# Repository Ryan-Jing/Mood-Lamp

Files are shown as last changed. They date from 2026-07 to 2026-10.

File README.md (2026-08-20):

# Mood-Lamp

Synchronized mood lamp between two paired devices. Each lamp is a Seeed XIAO ESP32-C3 with a
single WS2812B RGB LED and a dual-stage button. A lamp shows its **peer's** mood by default; you
set your own mood with the button, it's pushed to a small server, and the peer lamp polls and
renders it.

- **Firmware** (`Firmware/`) — PlatformIO + Arduino, two FreeRTOS tasks (UI + networking). See [`Firmware/README.md`](Firmware/README.md).
- **Server** (`Server/`) — FastAPI + SQLite on a Raspberry Pi, exposed publicly via Tailscale Funnel.
- **Utils** (`Utils/`) — `moods.yaml` (mood source of truth), the mood-header generator, and the BLE Wi-Fi provisioning script. See [`Utils/README.md`](Utils/README.md).
- **Docs** (`Docs/`) — architecture and CI/CD notes.
- **Electrical** / **Mechanical** — KiCad project and the printable enclosure STLs.

---

## Setup guide

### 1. Flash the firmware (first time only)

Skip to step 2 if the lamp is already flashed. Requires [PlatformIO Core](https://platformio.org/install/cli)
(`pio`) on your computer.

```bash
cd Firmware
```

```bash
cp include/secrets.example.h include/secrets.h
```

Open `include/secrets.h` and fill in `SERVER_URL`, `DEVICE_TOKEN` (one per lamp, from
`Server/database_init.py`), and `ROOT_CA`. Then connect the lamp by USB-C and flash it:

```bash
pio run -e seeed_xiao_esp32c3 -t upload
```

Do **not** press the lamp's button while flashing.

### 2. Power the lamp over USB-C

Plug the XIAO's USB-C port into any 5 V USB source (charger, laptop, power bank). The lamp boots
in about two seconds and the LED tells you where it is:

| LED | Meaning | What to do |
|---|---|---|
| Cyan blink | BLE provisioning — no Wi-Fi credentials saved | Go to step 3 |
| Warm-white breath | Connected, peer hasn't set a mood yet | Nothing, it's ready |
| Animated mood colour | Connected, showing the peer's mood | Nothing, it's ready |
| Orange blink | Wi-Fi problem | Re-provision (step 3) or check the network |

If the lamp already has credentials but you want to re-provision, hold the button fully pressed
for 5 seconds to force BLE provisioning on.

### 3. Send Wi-Fi credentials with `Utils/provision.py`

Do this on a computer with Bluetooth, within a few metres of the lamp, while the LED is blinking
cyan. Provisioning stays open for 2 minutes per session.

```bash
cd /path/to/Mood-Lamp
```

```bash
python3 -m venv .venv
```

```bash
source .venv/bin/activate
```

```bash
pip install bleak
```

```bash
python3 Utils/provision.py
```

The script prompts for the network name and password, finds the lamp advertising as `MoodLamp`,
and writes the credentials over BLE:

```
Wi-Fi SSID: MyNetwork
Wi-Fi password: ********
Scanning for 'MoodLamp' (the lamp LED should be blinking cyan)...
Connected. Sending credentials...
Credentials sent. Waiting for the lamp to connect to Wi-Fi...
Lamp status: connecting
```

The lamp saves the credentials to flash (they survive reboots and power loss), leaves BLE, and
joins the network. The LED stops blinking cyan within a few seconds. Notes:

- 2.4 GHz networks only — the ESP32-C3 has no 5 GHz radio.
- If the lamp isn't found, it's not in provisioning mode; hold the button fully pressed for
  5 seconds and run the script again.
- `python3 Utils/ble_check.py` lists nearby BLE devices if you want to confirm the lamp is
  advertising at all.

### 4. Using the button

The button is a dual-action pushbutton: pressing part-way is a **half press** (first detent), and
pressing all the way down is a **full press**. Every gesture fires when you *release*.

| Gesture | What it does |
|---|---|
| Half tap | Only in mood-select mode: step to the next mood |
| Full tap | Enter mood-select mode → then confirm the mood and send it to your peer |
| Full press, hold 5 s | Turn BLE provisioning on (or off if it's already on) |
| Full press, hold 10 s | Erase the saved Wi-Fi credentials and reopen BLE provisioning |

To set your mood:

1. **Full tap** — the LED switches from your peer's mood to your own. (This only works while the
   lamp is connected; if it isn't, nothing happens.)
2. **Half tap** repeatedly until the LED shows the mood you want. It wraps around from Working
   back to Excited.
3. **Full tap** — the mood is posted to the server and the LED goes back to showing your peer's
   mood. Their lamp picks it up within 10 seconds.

Half taps do nothing outside mood-select mode, so brushing the button won't change anything. Hold
times are measured from the moment the *full* stage engages, so resting at the half press first
doesn't count toward the 5 s and 10 s timers.

---

## Moods

Colours and patterns are defined in [`Utils/moods.yaml`](Utils/moods.yaml) and generated into
`Firmware/include/moods.h`. The ID below is the `mood_id` the firmware and server exchange.

Three **status** moods are shown by the lamp but are never user-selectable (mood-select skips
them):

| ID | Mood | Colour | Pattern | Period |
|---|---|---|---|---|
| 0 | Idle / default | soft warm white | breath | 6000 ms |
| 1 | BLE provisioning | cyan | blink | 1000 ms |
| 2 | No Wi-Fi | reddish orange | blink | 500 ms |

The user-selectable moods:

| ID | Mood | Colour(s) | Pattern | Period |
|---|---|---|---|---|
| 3 | Excited | bright yellow | breath | 1000 ms |
| 4 | Happy | rainbow (7 colours) | fade | 1000 ms |
| 5 | Sad | dark blue | breath | 3000 ms |
| 6 | Upset | dark red | breath | 1000 ms |
| 7 | Anxious | dark purple → purple → violet → red | breath alternate | 800 ms |
| 8 | Deep Breaths | dark green | breath | 8000 ms |
| 9 | Love | dark pink → pink → bright pink → light purple | fade | 1000 ms |
| 10 | Heepy | bright pink | blink | 800 ms |
| 11 | Hungry | dark brownish yellow | breath | 1000 ms |
| 12 | Tired | dark red ↔ dark orange | fade | 10000 ms |
| 13 | Working | warm orange | solid | — |

Patterns: `solid`, `blink` (on for the first half of the period), `breath` (dim → bright → dim),
`alternate` (hard switch between colours), `fade` (smooth cross-fade), and `breath_alternate`
(one breath per colour, advancing to the next each cycle).

To change moods, edit [`Utils/moods.yaml`](Utils/moods.yaml), then regenerate the firmware header
and re-flash:

```bash
cd /path/to/Mood-Lamp
```

```bash
python3 Utils/generate_moods.py
```

Both lamps must run the same mood table — IDs are what travel over the wire, so a lamp with an
older table will render the wrong mood.

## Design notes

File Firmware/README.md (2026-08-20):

# Mood Lamp — Firmware

Firmware for a two-device "mood lamp" pair. Each lamp is a Seeed XIAO ESP32-C3 with one
WS2812B RGB LED and one dual-stage pushbutton. A lamp's default display is the **peer's**
mood: the user sets their own mood locally with the button, the firmware pushes it to a
shared server over HTTPS, and the peer lamp polls the server and renders it as a
colour/pattern. Wi-Fi credentials are provisioned over BLE with `Utils/provision.py`.

For end-user setup (power, provisioning, button use), see the
[root README](../README.md#setup-guide); this document covers the firmware itself.

---

## Hardware

| Component | Part | Connection |
|---|---|---|
| MCU | Seeed XIAO ESP32-C3 (single-core RISC-V, Wi-Fi + BLE) | USB-C for power/flash/serial |
| RGB LED | SparkFun WS2812B Breakout (part 13282) | DIN → `D0` (GPIO2), DO unconnected |
| Button | E-Switch **PB300DTQ** dual-action pushbutton | pin 1 → GND, pin 2 → `D2` (GPIO4), pin 3 → `D1` (GPIO3) |

### Wiring notes

- **WS2812B**: single-wire self-clocked protocol, driven by the Adafruit NeoPixel library
  (`NEO_GRB + NEO_KHZ800`). Power the LED from **3.3 V**, not 5 V: with a 5 V supply the
  ~3.5 V logic-high threshold is above the ESP32-C3's 3.3 V output. At 3.3 V supply the LED
  is in spec, slightly dimmer.
- **Button**: both stage pins use internal pull-ups (`INPUT_PULLUP`), active low. No
  external resistors needed.
- **`D0` is GPIO2, an ESP32-C3 strapping pin** — it must be high or floating at reset. The
  WS2812B's DIN is a high-impedance input and the pin is only driven after boot, so normal
  boot and flashing are unaffected.
- Pin assignments live in `src/hal/led.cpp` (`LED_DIN_PIN`) and `src/hal/button.cpp`
  (`button_position_one` / `button_position_two`).

---

## Project setup

Built with [PlatformIO](https://platformio.org/) on the Arduino framework.

```sh
cd Firmware

# 1. Create your secrets file (never committed)
cp include/secrets.example.h include/secrets.h
#    ...then fill in SERVER_URL, DEVICE_TOKEN, and ROOT_CA (PEM string)

# 2. Build + flash + monitor (XIAO ESP32-C3 over USB)
pio run -e seeed_xiao_esp32c3 -t upload
pio device monitor            # 115200 baud

# 3. Run host-side unit tests (no hardware needed)
pio test -e native
```

Library dependencies (resolved automatically by PlatformIO): Adafruit NeoPixel,
NimBLE-Arduino, ArduinoJson.

`include/moods.h` is **auto-generated** — edit `Utils/moods.yaml` at the repo root and
re-run the generator (`Utils/generate_moods.py`) instead of editing it by hand.

Debug logging is controlled by `PRINT_DEBUG` in `include/config.h`; comment it out for a
quiet build. Note that with it enabled, received Wi-Fi credentials are echoed to serial.

---

## File structure

```
Firmware/
├── platformio.ini            # Envs: seeed_xiao_esp32c3 (target), native (unit tests)
├── include/
│   ├── config.h              # Timeouts, poll interval, retry limits, PRINT_DEBUG
│   ├── moods.h               # AUTO-GENERATED mood enum + colour/pattern table
│   ├── secrets.h             # Server URL, device token, root CA (from secrets.example.h)
│   ├── state.h               # LampState / NetState types + shared task interface
│   ├── hal/
│   │   ├── button.h          # ButtonState/ButtonEvent enums, gesture handler API
│   │   ├── led.h             # LED driver API
│   │   └── led_effects.h     # Pattern animation (pure logic, host-testable)
│   └── net/
│       ├── api.h             # HTTP mood-server client API
│       ├── ble.h             # BLE provisioning service API
│       └── wifi.h            # Wi-Fi connect + NVS credential storage API
├── src/
│   ├── main.cpp              # Entry point; vLampTask + vCommsTask state machines
│   ├── state.cpp             # Mutex/queue-backed shared state between the two tasks
│   ├── hal/
│   │   ├── button.cpp        # Debounce, press-cycle event decoding, gesture handlers
│   │   ├── led.cpp           # WS2812B driver (Adafruit NeoPixel, GPIO2)
│   │   └── led_effects.cpp   # Solid/blink/breath/alternate/fade frame computation
│   └── net/
│       ├── api.cpp           # HTTPS POST/GET of moods (Bearer auth, ETag polling)
│       ├── ble.cpp           # NimBLE provisioning service (SSID/pass/apply/status)
│       └── wifi.cpp          # STA connect + Preferences (NVS) credential store
├── test/
│   └── test_logic/           # Unity tests for led_effects (run via `pio test -e native`)
└── docs/                     # Doxygen styling (see Doxyfile)
```

### Architecture

Two FreeRTOS tasks, created in `setup()`, communicate only through the mutex/queue-guarded
interface in `state.cpp`:

- **`vLampTask`** — reads the button, runs the `AppState` machine, renders the LED every
  10 ms. Never blocks on the network.
- **`vCommsTask`** — runs the `CommsStatus` machine: BLE provisioning, Wi-Fi connection,
  SNTP time sync, and server sync. Receives user commands (start/stop BLE, clear Wi-Fi)
  from the lamp task via a queue.

---

## Button (PB300DTQ)

The E-Switch **PB300DTQ** is a momentary double-action pushbutton: the first circuit
closes at mid travel and the second at full travel (2.0 mm total; ~600 g to the first
detent, ~1150 g to the second). Pin 1 is common (GND); pin 2 grounds at **half press**
(→ `D2`) and pin 3 grounds additionally at **full press** (→ `D1`). At full press both
signal pins are shorted to GND.

### Debounce and states

`get_button_state()` debounces each stage pin independently (50 ms) and folds them into
one `ButtonState`:

| `D2` (half stage) | `D1` (full stage) | State |
|---|---|---|
| HIGH | HIGH | `BUTTON_RELEASED` |
| LOW | HIGH | `BUTTON_HALF_PRESSED` |
| any | LOW | `BUTTON_FULL_PRESSED` |

The full stage alone decides `BUTTON_FULL_PRESSED`, since a full press grounds both pins.

### Events

A full press mechanically passes through the half stage on the way down *and* up, so raw
states can't be used as gestures directly. `update_button_event()` tracks each press
cycle (latching whether it ever reached full) and emits **one event on release**:

| Event | Meaning |
|---|---|
| `BUTTON_EVENT_HALF_TAP` | Pressed and released without ever reaching the full stage |
| `BUTTON_EVENT_FULL_TAP` | Reached full, released before `BLE_SET_TIMER` (5 s) |
| `BUTTON_EVENT_FULL_HOLD_BLE` | Full stage held ≥ 5 s and < 10 s |
| `BUTTON_EVENT_FULL_HOLD_WIFI` | Full stage held ≥ `WIFI_CLEAR_TIMER` (10 s) |

Hold time is measured from when the **full** stage engages — resting at half press first
doesn't count toward the timers.

### Gesture map

`handle_user_button_commands()` consumes global gestures first; per-state handlers
(`show_mood_button_handle` / `select_mood_button_handle`) get unconsumed events.

| Gesture | SHOW_MOOD | SELECT_MOOD | BLE provisioning/connected |
|---|---|---|---|
| Half tap | — | Cycle to next mood | — |
| Full tap | Enter SELECT_MOOD (requires `NET_CONNECTED`) | Confirm: post mood, back to SHOW_MOOD | **Exit BLE immediately** (`USER_COMMAND_STOP_BLE`) |
| Full hold 5 s | Start BLE provisioning | Start BLE provisioning | Stop BLE |
| Full hold 10 s | Clear Wi-Fi credentials → re-enter provisioning | same | same |

Half taps are deliberately inert outside SELECT_MOOD: the half stage is easy to hit, so
casual presses in SHOW_MOOD do nothing.

### Lamp application states (`AppState`)

| State | LED shows | Entered by |
|---|---|---|
| `SHOW_MOOD` | Peer's mood (or `IDLE` pattern if disconnected) | Default; comms status `NET_*` |
| `SELECT_MOOD` | Your own candidate mood while scrolling | Full tap in SHOW_MOOD |
| `BLE_STATUS` | `BLE` pattern (cyan blink) | Comms status `BLE_PROVISIONING` / `BLE_CONNECTED` |
| `NET_STATUS` | `NO_WIFI` pattern (orange blink) | (reserved) |

`SELECT_MOOD` is exited by confirming a mood, or automatically if the network drops.

---

## LED (WS2812B)

One WS2812B pixel on `D0` (GPIO2), driven by Adafruit NeoPixel. Every lamp-task
iteration calls `led_render(mood)`, which looks up the mood's `MoodDefinition` (up to
`MAX_MOOD_COLOURS` = 8 RGB colours, a pattern, and a period) and computes the current frame
with `mood_frame()` in `led_effects.cpp` — pure logic with no hardware dependency, which is
what the native unit tests cover. `led_render` only re-latches the pixel when the computed
colour changes.

Patterns: `SOLID`, `BLINK` (on for the first half of the period), `BREATH` (raised-cosine,
gamma-corrected brightness ramp), `ALTERNATE` (hard switch between colours each period),
`FADE` (smooth cross-fade between colours), `BREATH_ALTERNATE` (one breath per colour,
advancing to the next each cycle). A `period` of 0 renders the base colour solid.

The mood table is generated from `Utils/moods.yaml` into `moods.h`, and the enum index is
the `mood_id` exchanged with the server (`MOOD_COUNT` = 14). The first three entries are
**status** moods, never user-selectable; scrolling to pick a mood starts at
`FIRST_SELECTABLE_MOOD` (`MOOD_1`) and wraps back to it:

| ID | Enum | Mood | Colour(s) | Pattern | Period |
|---|---|---|---|---|---|
| 0 | `IDLE` | Default | soft warm white | breath | 6000 ms |
| 1 | `BLE` | BLE Provisioning | cyan | blink | 1000 ms |
| 2 | `NO_WIFI` | No Wi-Fi | reddish orange | blink | 500 ms |
| 3 | `MOOD_1` | Excited | bright yellow | breath | 1000 ms |
| 4 | `MOOD_2` | Happy | rainbow (7 colours) | fade | 1000 ms |
| 5 | `MOOD_3` | Sad | dark blue | breath | 3000 ms |
| 6 | `MOOD_4` | Upset | dark red | breath | 1000 ms |
| 7 | `MOOD_5` | Anxious | dark purple → purple → violet → red | breath alternate | 800 ms |
| 8 | `MOOD_6` | Deep Breaths | dark green | breath | 8000 ms |
| 9 | `MOOD_7` | Love | dark pink → pink → bright pink → light purple | fade | 1000 ms |
| 10 | `MOOD_8` | Heepy | bright pink | blink | 800 ms |
| 11 | `MOOD_9` | Hungry | dark brownish yellow | breath | 1000 ms |
| 12 | `MOOD_10` | Tired | dark red ↔ dark orange | fade | 10000 ms |
| 13 | `MOOD_11` | Working | warm orange | solid | — |

---

## Communication

### Comms state machine (`CommsStatus`, in `vCommsTask`)

At boot the task starts in `BLE_PROVISIONING` if NVS holds no credentials, otherwise in
`NET_CONNECTING`.

| State | What it does | Leaves to |
|---|---|---|
| `BLE_PROVISIONING` | Advertises as `MoodLamp` and waits for a client | `BLE_CONNECTED` on connect; after the 2 min timeout or a full tap, back to `NET_CONNECTING` (saved creds) or `NET_DISCONNECTED` (none) |
| `BLE_CONNECTED` | Receives SSID/password, saves them to NVS on Apply | `NET_CONNECTING` once credentials are applied; `BLE_PROVISIONING` if the client drops |
| `NET_CONNECTING` | Joins Wi-Fi (20 s timeout per attempt), then waits for SNTP time sync (needed for TLS certificate validation); retries every 5 s | `NET_CONNECTED` on success; `NET_DISCONNECTED` after 12 failed attempts |
| `NET_CONNECTED` | Uploads any locally-set mood and polls the peer's mood | `NET_CONNECTING` after 5 consecutive API failures or a Wi-Fi drop |
| `NET_DISCONNECTED` | Idle; the lamp shows the `IDLE` pattern | Only by user command (button) |

A 5 s full hold starts or stops BLE provisioning from any state; a 10 s full hold clears
the stored credentials and returns to `BLE_PROVISIONING`.

### BLE provisioning

NimBLE GATT server, device name `MoodLamp`, active for at most 2 minutes per session
(`BLE_PROVISIONING_TIMEOUT_MS`). Service `9a1e0000-8f4a-4b1c-9e2a-1234567890ab`:

| Characteristic | UUID suffix | Access | Purpose |
|---|---|---|---|
| SSID | `...0001` | write | Wi-Fi SSID (max 32 chars) |
| Password | `...0002` | write | Wi-Fi password (max 63 chars) |
| Apply | `...0003` | write | Any write commits the credentials |
| Status | `...0004` | read/notify | `"provisioning"` → `"connecting"` |

Flow: `Utils/provision.py` writes SSID and password, then writes Apply. The comms task saves
the credentials to NVS (`Preferences`, namespace `wifi`), notifies `"connecting"` on
Status, tears down BLE, and moves to `NET_CONNECTING`. Credentials persist across reboots;
a 10 s full-press hold wipes them and returns to provisioning.

### Server API

HTTPS with certificate pinning (`ROOT_CA`) and per-device Bearer token auth
(`DEVICE_TOKEN`), both from `secrets.h`. The server pairs exactly two devices; "peer"
below is resolved server-side from the token. 5 s request timeout (`API_TIMEOUT_MS`).

**`POST /v1/mood`** — publish this lamp's mood.

```json
{ "mood_id": 6 }
```

**`GET /v1/peer/mood`** — fetch the peer's mood, polled every 10 s
(`PEER_POLL_INTERVAL_MS`). Responses are versioned: the lamp sends
`If-None-Match: "<version>"` and the server replies `304 Not Modified` when nothing
changed, so steady-state polling transfers no body. On change:

```json
{ "mood_id": 6, "version": 42 }
```

`mood_id` is validated against `MOOD_COUNT` before use; malformed responses count toward
the retry limit like HTTP errors.

### Hosting & the `ts.net` DNS gotcha

The server runs on a Raspberry Pi (CM5) and is exposed to the public internet via **Tailscale
Funnel**, so `SERVER_URL` is a `*.ts.net` hostname reachable from anywhere — the ESP32 never
joins the tailnet, it just makes ordinary HTTPS requests to the public Funnel URL.

One gotcha worth knowing: many home routers' **DNS rebind protection blocks `*.ts.net`**
(Tailscale names can resolve into the CGNAT `100.64.0.0/10` range, which rebind protection
treats as suspicious), so the router refuses to resolve the server hostname even though public
resolvers do. Symptom on the lamp:

```
[E][WiFiGeneric.cpp:1583] hostByName(): DNS Failed for <server>.ts.net
```

The firmware works around this by forcing public DNS (`8.8.8.8` / `1.1.1.1`) via
`force_public_dns()` in `wifi.cpp`. It must run **after** `WL_CONNECTED` — once DHCP has
assigned its own DNS — otherwise DHCP overwrites the override. It re-applies on every
`wifi_connect()`, so a DHCP lease renewal that resets DNS self-heals on the next reconnect.

If a lamp on a **new** network still fails after this, that router is *intercepting* outbound
DNS (forcing port 53 through itself); disable DNS rebind protection or allowlist `ts.net` on
that router. Quick confirm via `PRINT_DEBUG`: `DNS1: 8.8.8.8` plus `example.com` resolving but
the server failing pinpoints the `ts.net`-specific block.

> Verifying the server side (from any machine): `dig @8.8.8.8 <server>.ts.net` should return
> Tailscale Funnel IPs, and `curl https://<server>.ts.net/v1/health` should return
> `{"ok":true}`. On the Pi, `tailscale funnel status` should show `/ proxy` to the uvicorn port.

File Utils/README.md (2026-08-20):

# Utils

Host-side tooling: the mood definitions and their code generator, plus the BLE Wi-Fi
provisioning script.

| File | Purpose |
|---|---|
| `moods.yaml` | Single source of truth for every mood's colour(s), pattern, and period |
| `generate_moods.py` | Bakes `moods.yaml` into `Firmware/include/moods.h` |
| `provision.py` | Sends Wi-Fi credentials to a lamp over BLE |
| `ble_check.py` | Lists nearby BLE devices — used to confirm a lamp is advertising |
| `Button-Test/` | Standalone PlatformIO sketch for bench-testing the dual-stage button |

Run every script from the repo root; they resolve paths relative to their own location.

---

## `provision.py`

Connects to a Mood Lamp over BLE and hands it a Wi-Fi SSID and password, so the lamp can
join the network and reach the server. It targets the GATT service in
`Firmware/src/net/ble.cpp` — device name `MoodLamp`, service
`9a1e0000-8f4a-4b1c-9e2a-1234567890ab`, with SSID / password / apply / status
characteristics. See [`Docs/architecture.md`](../Docs/architecture.md) for the full layout.

```bash
cd /path/to/Mood-Lamp
```

```bash
python3 -m venv .venv
```

```bash
source .venv/bin/activate
```

```bash
pip install bleak
```

Put the lamp in provisioning mode first — it's already there on first boot (LED blinking
cyan), otherwise hold the button fully pressed for 5 seconds. Provisioning stays open for
2 minutes. Then:

```bash
python3 Utils/provision.py
```

Enter the SSID and password at the prompts. The lamp stores them in NVS, drops BLE, and
joins Wi-Fi; the script prints the lamp's status notification before exiting. A 10 s full
button hold erases the stored credentials and reopens provisioning.

If the scan times out, check that the lamp is advertising:

```bash
python3 Utils/ble_check.py
```

## `generate_moods.py`

Regenerates `Firmware/include/moods.h` from `moods.yaml`. That header is **auto-generated**
— never edit it by hand.

```bash
pip install pyyaml
```

```bash
python3 Utils/generate_moods.py
```

Re-flash both lamps afterwards: the enum index is the `mood_id` sent over the wire, so
lamps running different mood tables will render different moods. The mood chart lives in
the [root README](../README.md#moods).

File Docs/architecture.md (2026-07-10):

# Mood Lamp - Architecture

Two paired ESP32 mood lamps share state through a small server. Each lamp shows the peer's mood by
default, while the local button selects this device's own mood and posts it to the server.

## Key Decisions

| Area | Current choice | Notes |
|---|---|---|
| MCU | Seeed XIAO ESP32-C3 | Single-core RISC-V board with Wi-Fi and BLE. |
| Firmware | PlatformIO + Arduino-ESP32 | Uses FreeRTOS tasks from the Arduino core. |
| LED | Single WS2812B/NeoPixel-style RGB LED | Driven by `Adafruit_NeoPixel` on `LED_DIN_PIN`. |
| Provisioning | NimBLE GATT + Python scripts in `Utils/` | BLE is used to send Wi-Fi SSID/password only. |
| Device-to-server | HTTPS polling | The ESP32 posts its mood and polls the peer mood about every 10 seconds. |
| Server | FastAPI + SQLite on the RPi CM5 | `uvicorn` runs under `systemd`; Tailscale Funnel provides public HTTPS. |
| Auth | Per-device bearer token | The server hashes stored tokens and derives identity from the bearer token. |

The server must never trust a device ID from the request body. A device proves who it is with its
bearer token, then the server decides which pair and peer it is allowed to access.

## Repository Layout

```text
Mood-Lamp/
|-- Docs/
|   |-- architecture.md
|   `-- ci-cd.md
|-- Firmware/
|   |-- include/
|   |   |-- config.h
|   |   |-- moods.h                 # generated from Utils/moods.yaml
|   |   |-- secrets.example.h       # safe placeholder for CI/public repo
|   |   |-- secrets.h               # ignored local secrets file
|   |   |-- state.h
|   |   |-- hal/
|   |   `-- net/
|   |-- src/
|   |   |-- main.cpp                # task creation and top-level state loops
|   |   |-- state.cpp               # mutex/queue shared task interface
|   |   |-- hal/
|   |   `-- net/
|   |-- test/
|   `-- platformio.ini
|-- Server/
|   |-- app.py                     # FastAPI API
|   `-- database_init.py           # SQLite schema + token generation
|-- Utils/
|   |-- moods.yaml                 # source of truth for mood IDs
|   |-- generate_moods.py          # YAML -> Firmware/include/moods.h
|   |-- ble_check.py
|   `-- provision.py
`-- .github/workflows/ci.yml
```

`Utils/moods.yaml` is the mood source of truth. After changing it, regenerate
`Firmware/include/moods.h` with `python Utils/generate_moods.py`.

## Firmware Architecture

### Module Layout

```text
Firmware/include/                 Firmware/src/
|-- config.h                      |-- main.cpp
|-- moods.h                       |-- state.cpp
|-- state.h                       |-- hal/
|-- secrets.example.h             |   |-- button.cpp
|-- secrets.h                     |   |-- led.cpp
|-- hal/                          |   `-- led_effects.cpp
|   |-- button.h                  `-- net/
|   |-- led.h                         |-- api.cpp
|   `-- led_effects.h                 |-- ble.cpp
`-- net/                              `-- wifi.cpp
    |-- api.h
    |-- ble.h
    `-- wifi.h
```

Important boundaries:

- `main.cpp` owns the two FreeRTOS tasks and the top-level state transitions.
- `state.cpp/h` owns cross-task communication: mutex-protected comms state and peer mood, plus queues
  for posted moods and user commands.
- `button.cpp` reads/debounces the physical button and converts gestures into state changes or
  `UserCommand` messages.
- `led_effects.cpp` is pure animation math and is compiled into native unit tests.
- `led.cpp` is hardware-facing and owns `Adafruit_NeoPixel`.
- `wifi.cpp` owns Wi-Fi connect/disconnect and NVS Wi-Fi credential storage.
- `ble.cpp` owns the BLE provisioning GATT service.
- `api.cpp` owns HTTPS calls to the FastAPI server.

### Task Model

The firmware runs two long-lived tasks:

- `vLampTask` is the UI task. It reads the button every 10 ms, chooses the lamp state, and renders the
  LED. It should stay non-blocking.
- `vCommsTask` is the network task. It owns BLE, Wi-Fi, SNTP readiness, HTTP requests, API retry
  counting, and NVS Wi-Fi credential operations. This task may block on network operations.

The tasks share only small pieces of data:

- `CommsStatus` through `shared_set_net_state()` / `shared_get_net_state()`.
- Peer mood through `shared_set_peer_mood()` / `shared_get_peer_mood()`.
- Local mood posts through `shared_post_mood()` / `shared_get_posted_mood()`.
- Long-hold user commands through `shared_post_user_command()` / `shared_take_user_command()`.

### State Model

`LampState` is local to `vLampTask`.

| Field | Meaning |
|---|---|
| `self_mood` | This lamp's locally selected mood. This is posted to the server and shown on the peer lamp. |
| `peer_mood` | The paired lamp's latest mood. This is what this lamp displays in normal mode. |
| `application_state` | UI/rendering state: `BLE_STATUS`, `NET_STATUS`, `SHOW_MOOD`, or `SELECT_MOOD`. |
| `button_state` / timers | Debounced input and hold-duration bookkeeping. |

`NetState` is local to `vCommsTask`.

| Field | Meaning |
|---|---|
| `comms_status` | Network state: `BLE_PROVISIONING`, `BLE_CONNECTED`, `NET_CONNECTING`, `NET_CONNECTED`, or `NET_DISCONNECTED`. |
| `wifi_credentials` | Last loaded or newly provisioned Wi-Fi SSID/password. |
| `peer_mood` / `peer_version` | Last peer mood returned by the server and its ETag/version. |
| `mood_to_post` / `has_mood_to_post` | Pending local mood that must be sent to the server. |
| `ble_provisioning_started_ms` | Time BLE provisioning entered advertising mode, used for the no-connection timeout. |
| `wifi_retry_count` / `poll_retry_count` | Retry counters used before backing out of network work. |

### Button Gestures

Most button behavior is intentionally decided on release so one hold does not trigger multiple
actions. The BLE exit gesture is handled as soon as the hold reaches `BLE_SET_TIMER` while BLE is
active so it cannot fall through to the longer Wi-Fi clear gesture.

| Gesture | State requirement | Result |
|---|---|---|
| Short press | `SELECT_MOOD` | Cycle `self_mood`. |
| Hold `MOOD_SET_TIMER` to `BLE_SET_TIMER` | `SHOW_MOOD` and `NET_CONNECTED` | Enter `SELECT_MOOD`. |
| Hold `MOOD_SET_TIMER` to `BLE_SET_TIMER` | `SELECT_MOOD` and `NET_CONNECTED` | Post `self_mood` and return to `SHOW_MOOD`. |
| Hold at least `BLE_SET_TIMER` | `BLE_PROVISIONING` or `BLE_CONNECTED` | Stop BLE provisioning and return to normal mood display. |
| Hold `BLE_SET_TIMER` to `WIFI_CLEAR_TIMER` | Not in BLE mode | Start BLE provisioning with `USER_COMMAND_START_BLE`. |
| Hold at least `WIFI_CLEAR_TIMER` | Not in BLE mode | Clear NVS Wi-Fi credentials and start BLE provisioning. |

If BLE provisioning is advertising and no central connects within `BLE_PROVISIONING_TIMEOUT_MS`,
the comms task stops BLE and resumes the normal network state: `NET_CONNECTING` when saved Wi-Fi
credentials are present, otherwise `NET_DISCONNECTED`.

Mood selection is blocked when the lamp is not connected to the server. If Wi-Fi/API connectivity is
lost while selecting a mood, the lamp returns to `SHOW_MOOD`.

### LED Pipeline

```text
Utils/moods.yaml
    |
    `-- Utils/generate_moods.py
            |
            `-- Firmware/include/moods.h
                    |
                    `-- get_mood_definition(mood)
                            |
                            `-- mood_frame(def, millis(), r, g, b)
                                    |
                                    `-- led_write(r, g, b)
```

`led_effects.cpp` contains the testable animation function `mood_frame()`. `led.cpp` wraps that pure
logic with the physical NeoPixel driver.

### BLE, Wi-Fi, and NVS

On boot, the comms task checks NVS for Wi-Fi credentials:

- If no credentials exist, the device starts BLE provisioning.
- If credentials exist, BLE stays off and the device tries to connect to Wi-Fi.

The BLE service advertises as `MoodLamp` and exposes characteristics for:

- SSID write
- password write
- apply write
- status read/notify

When the Python provisioning script writes SSID/password and then writes the apply characteristic,
`vCommsTask` saves the credentials to NVS, notifies `"connecting"`, stops BLE, and transitions to
`NET_CONNECTING`.

Only Wi-Fi credentials are stored in NVS today. Server configuration lives in the ignored local
`Firmware/include/secrets.h` file:

```cpp
#define SERVER_URL "https://your-tailnet-or-funnel-host"
#define DEVICE_TOKEN "one-device-token-from-database_init.py"
#define ROOT_CA R"EOF(
-----BEGIN CERTIFICATE-----
...
-----END CERTIFICATE-----
)EOF"
```

The public `secrets.example.h` exists only so CI and new clones can compile without real secrets.

### Network Behavior

After Wi-Fi joins, `api_wait_for_time()` waits for SNTP before HTTPS requests. This matters because
certificate validation requires a sane system time.

When connected:

- pending local moods are sent with `POST /v1/mood`;
- the peer mood is polled with `GET /v1/peer/mood`;
- the last known server `version` is sent as `If-None-Match`;
- a `304 Not Modified` response is treated as a successful no-op.

If Wi-Fi drops or API calls repeatedly fail, the comms task disconnects Wi-Fi and returns to
`NET_CONNECTING`. After the configured Wi-Fi retry limit, it enters `NET_DISCONNECTED`; the lamp shows
the idle mood until the user chooses to re-enter BLE provisioning or clear Wi-Fi credentials.

## Server Architecture

The current server is a small FastAPI application backed by SQLite:

- `Server/app.py` defines the API.
- `Server/database_init.py` creates the database tables and prints raw device tokens once.
- `MOOD_DB` selects the database path.
- `MOOD_COUNT` controls the valid mood ID range.

The intended production shape on the RPi CM5 is:

```text
ESP32
  |
  | HTTPS
  v
Tailscale Funnel hostname
  |
  | proxy to localhost
  v
uvicorn on 127.0.0.1:8000
  |
  v
FastAPI app + SQLite database
```

Tailscale Funnel terminates public HTTPS and proxies to local HTTP on the Pi. The FastAPI process can
therefore bind to `127.0.0.1:8000` under `systemd`; it does not need to listen directly on the public
network.

### Data Model

`database_init.py` creates three tables:

| Table | Purpose |
|---|---|
| `pairs` | Pair records, keyed by `pair_id`. |
| `devices` | Device records with `device_id`, `pair_id`, `display_name`, `token_hash`, and `last_seen`. |
| `mood_state` | Current mood for each device: `device_id`, `mood_id`, `version`, and `updated_at`. |

The raw device token is printed only when the device row is first created. The database stores only
`sha256(token)`, so a lost token should be replaced by creating/updating that device's token.

### API

| Endpoint | Auth | Purpose |
|---|---|---|
| `GET /v1/health` | No | Liveness check. |
| `GET /v1/me` | Bearer token | Debug/identity check for the current token. |
| `POST /v1/mood` | Bearer token | Set the caller's own mood. Body: `{ "mood_id": 4 }`. |
| `GET /v1/peer/mood` | Bearer token | Return the paired device's mood, version, and update time. |

`POST /v1/mood` validates `mood_id` using Pydantic: `0 <= mood_id < MOOD_COUNT`.

`GET /v1/peer/mood` requires exactly one peer in the caller's pair. It returns an `ETag` based on the
peer mood version. If the ESP32 sends the matching `If-None-Match` value, the server returns `304`.

### Security Notes

Safe to commit:

- source code;
- `Firmware/include/secrets.example.h`;
- docs;
- generated `Firmware/include/moods.h` if you want the firmware build to work without rerunning the
  generator.

Do not commit:

- `Firmware/include/secrets.h`;
- `.env`;
- SQLite databases such as `mood.db`;
- raw device tokens;
- private keys, PEM files, or certificate material you intend to keep private;
- `.venv`, `__pycache__`, `.pyc`, PlatformIO build output, and firmware binaries.

BLE provisioning is currently a convenience channel for Wi-Fi setup, not a hardened ownership flow.
Anyone nearby who can connect while provisioning is active may be able to write Wi-Fi credentials. Keep
BLE off during normal operation, and consider passkey bonding or an app-side pairing secret before
using this outside a trusted environment.

## Build Order

The current project has these pieces in place:

1. LED/button HAL and mood animation logic.
2. Two-task firmware state model.
3. BLE Wi-Fi provisioning into NVS.
4. Wi-Fi connect/retry/disconnect behavior.
5. FastAPI + SQLite mood server.
6. HTTPS polling client on the ESP32.
7. CI firmware build, native tests, and cppcheck.

Useful next work:

1. Stop printing Wi-Fi passwords in debug logs before sharing logs or demos.
2. Add native tests around the button gesture/state-machine behavior.
3. Add server-side tests for auth, mood validation, pair isolation, and ETag/304 behavior.
4. Add a real deployment note for renewing/replacing the ESP32 trusted root CA.

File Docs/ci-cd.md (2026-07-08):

# Mood Lamp - Firmware CI/CD

Automated checks are centered on the ESP32 firmware: compile the real target, run host-side unit tests
for portable logic, and run cppcheck before code reaches `main`.

## Overview

| Stage | Where | Tool | Gate? |
|---|---|---|---|
| Firmware compile | GitHub Actions | PlatformIO `pio run -e seeed_xiao_esp32c3` | Yes |
| Native unit tests | GitHub Actions | PlatformIO `native` env + Unity | Yes |
| Static analysis | GitHub Actions + local pre-push | cppcheck as C++17 | Yes |
| API docs | Local only | Doxygen | No |

This project is PlatformIO + Arduino on a Seeed XIAO ESP32-C3. It does not use ESP-IDF CI, Docker,
or QEMU boot tests. The useful CI signal today is:

- compile the actual firmware against the Arduino/PlatformIO toolchain;
- unit-test hardware-independent logic on the host;
- run cppcheck with the same settings locally and in CI.

## GitHub Actions

`.github/workflows/ci.yml` runs on pushes and pull requests to `main`.

### `build`

The build job:

1. checks out the repo;
2. installs Python 3.11;
3. caches PlatformIO and pip downloads;
4. installs PlatformIO and PyYAML;
5. regenerates `Firmware/include/moods.h` from `Utils/moods.yaml`;
6. copies `Firmware/include/secrets.example.h` to `Firmware/include/secrets.h`;
7. runs `pio run -e seeed_xiao_esp32c3` from `Firmware/`;
8. uploads the generated `.bin` files as a workflow artifact.

The artifact is a compile artifact, not a ready-to-deploy private firmware image. It is built with the
placeholder values from `secrets.example.h`, so server communication will not work until a local build
uses a real `Firmware/include/secrets.h`.

### `native-test`

The native test job:

1. installs PlatformIO and PyYAML;
2. regenerates `moods.h`;
3. creates the placeholder `secrets.h`;
4. runs `pio test -e native`.

The `native` environment in `Firmware/platformio.ini` intentionally compiles only portable source:

```ini
build_src_filter = -<*> +<hal/led_effects.cpp>
```

This keeps host tests away from Arduino-only hardware code such as `digitalRead`, Wi-Fi, NimBLE, and
`Adafruit_NeoPixel`. The current native test surface is the mood animation logic in `mood_frame()`.

### `cppcheck`

The static-analysis job:

1. installs PyYAML and cppcheck;
2. regenerates `moods.h`;
3. creates the placeholder `secrets.h`;
4. runs cppcheck inside `Firmware/`.

Current command:

```bash
cppcheck --enable=warning,style,performance,portability \
  --std=c++17 --language=c++ --error-exitcode=1 --inline-suppr \
  -I include \
  --suppressions-list=.cppcheck-suppressions \
  src
```

`--error-exitcode=1` makes any reported finding fail the job. `--inline-suppr` allows deliberate
source-level suppressions, and `.cppcheck-suppressions` covers expected false positives such as
missing Arduino/library include paths.

## Secrets in CI

`Firmware/include/secrets.h` is intentionally ignored by git because it contains:

```cpp
#define SERVER_URL "https://..."
#define DEVICE_TOKEN "..."
#define ROOT_CA "..."
```

Ignoring that file is correct, but the firmware includes `secrets.h`, so CI still needs a file with
that name. The repository solves this with `Firmware/include/secrets.example.h`, which contains dummy
values. Each CI job copies the example into place before building, testing, or running cppcheck:

```bash
cp Firmware/include/secrets.example.h Firmware/include/secrets.h
```

Rules:

- commit `secrets.example.h`;
- never commit `secrets.h`;
- do not flash CI artifacts to real devices unless you intentionally provide real secrets during that
  build;
- do not put raw device tokens into workflow logs.

## Local Setup

Enable the pre-push hook once per clone:

```bash
chmod +x .githooks/pre-push
git config core.hooksPath .githooks
```

Install local tools:

```bash
brew install cppcheck doxygen
python3 -m venv .venv
source .venv/bin/activate
pip install platformio pyyaml
```

Generate the mood table after changing `Utils/moods.yaml`:

```bash
python Utils/generate_moods.py
```

Create `Firmware/include/secrets.h` before local firmware builds. For compile-only work, the example
is enough:

```bash
cp Firmware/include/secrets.example.h Firmware/include/secrets.h
```

For flashing a real lamp, edit `Firmware/include/secrets.h` with that device's real server URL, token,
and trusted root CA.

## Running Locally

From the repo root:

```bash
python Utils/generate_moods.py
```

From `Firmware/`:

```bash
pio run -e seeed_xiao_esp32c3
pio test -e native
doxygen Doxyfile
cppcheck --enable=warning,style,performance,portability \
  --std=c++17 --language=c++ --error-exitcode=1 --inline-suppr \
  -I include \
  --suppressions-list=.cppcheck-suppressions \
  src
```

The pre-push hook currently runs cppcheck only. It does not run `pio run` or `pio test`, so run those
manually before pushing larger firmware changes.

## Generated Files and Ignored Files

Expected generated or local-only files:

| Path/pattern | Reason |
|---|---|
| `Firmware/include/secrets.h` | Real server URL, token, and trusted root CA. |
| `.venv/`, `Server/.venv/` | Python virtual environments. |
| `__pycache__/`, `*.pyc` | Python bytecode cache. |
| `*.db`, `*.sqlite`, `*.sqlite3` | Local server databases with token hashes and device state. |
| `*.pem`, `*.key` | Certificate/private-key material. |
| `Firmware/.pio/` | PlatformIO build/cache output. |
| `Docs/doxygen/` | Generated Doxygen documentation. |
| `*.bin`, `*.elf`, `*.map` | Firmware build artifacts. |

## Open Items

1. Add native tests for button gesture handling once the state-machine logic is isolated from the
   Arduino GPIO calls.
2. Add server tests for auth failure, pair isolation, mood validation, and `ETag`/`304` polling.
3. Consider a CI drift check that regenerates `moods.h` and fails if `git diff --exit-code` is not
   clean.
4. Decide whether release firmware should ever be built in CI with encrypted GitHub secrets, or only
   built locally on trusted machines.

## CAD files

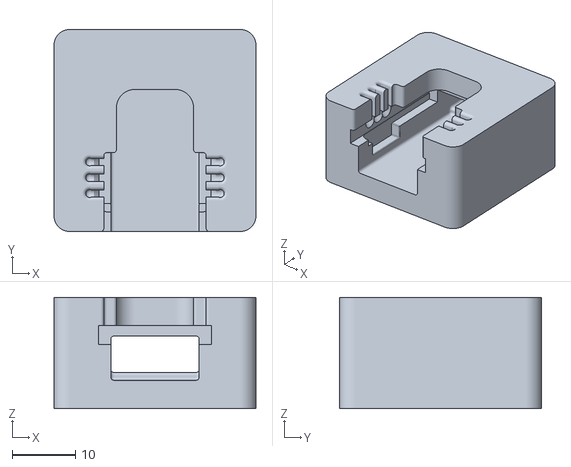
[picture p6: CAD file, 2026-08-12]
Mechanical/CAD/Main Housing - FINAL.stl
32.0 x 32.0 x 17.7

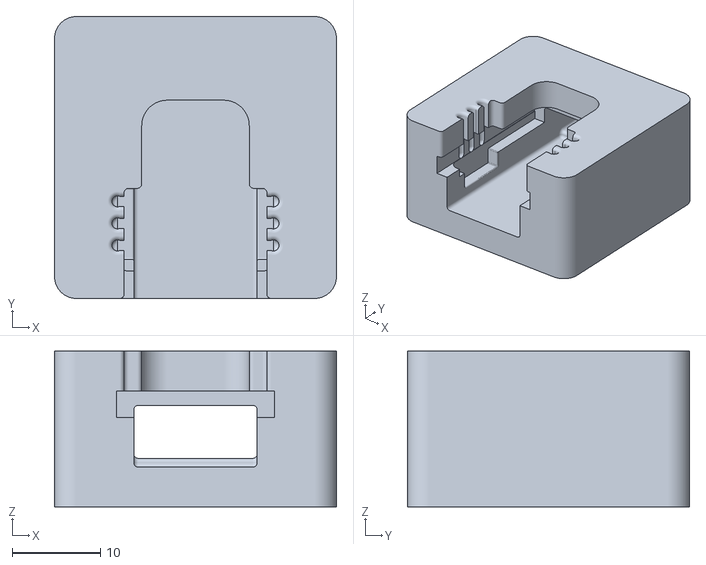
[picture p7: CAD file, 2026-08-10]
Mechanical/CAD/Main Housing - V6.stl
32.0 x 32.0 x 17.7

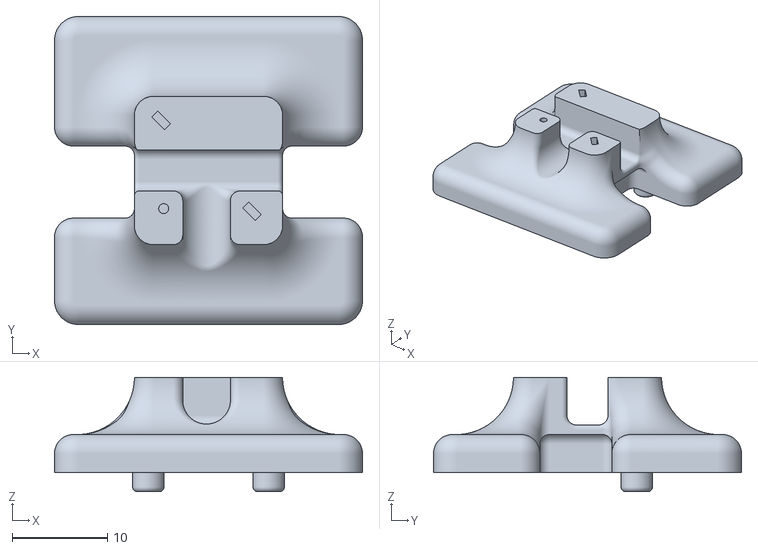
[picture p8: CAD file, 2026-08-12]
Mechanical/CAD/Button Board - FINAL.stl
32.3 x 32.3 x 12.0

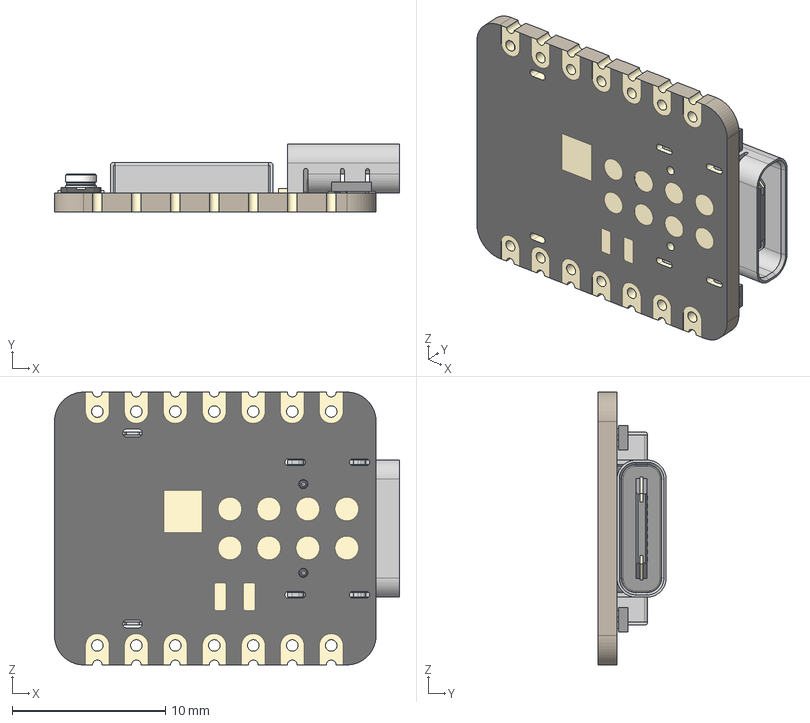
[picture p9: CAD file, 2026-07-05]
Mechanical/Components/ESP32XIAO/seeed-studio-xiao-esp32s3-1/XIAO-ESP32S3 v2.step
22.5 x 4.46 x 17.8 mm
BOSS-EXTRUDE14_8_
BOSS-EXTRUDE7_4_
BOSS-EXTRUDE7_3_
BOSS-EXTRUDE14_4_
BOSS-EXTRUDE14_2_
BOSS-EXTRUDE14_11_
BOSS-EXTRUDE7_7_
BOSS-EXTRUDE14_9_
BOSS-EXTRUDE14_3_
BOSS-EXTRUDE14_7_
MIRROR2
BOSS-EXTRUDE14_5_
BOSS-EXTRUDE14_12_
BOSS-EXTRUDE7_8_
BOSS-EXTRUDE7_1_
BOSS-EXTRUDE14_10_
BOSS-EXTRUDE7_9_
BOSS-EXTRUDE14_6_
BOSS-EXTRUDE14_1_
BOSS-EXTRUDE7_6_
BOSS-EXTRUDE7_2_
CUT-EXTRUDE5
BOSS-EXTRUDE7_5_
Shield
Pins x 2
U.FL-R-SMT-1_10_ v1

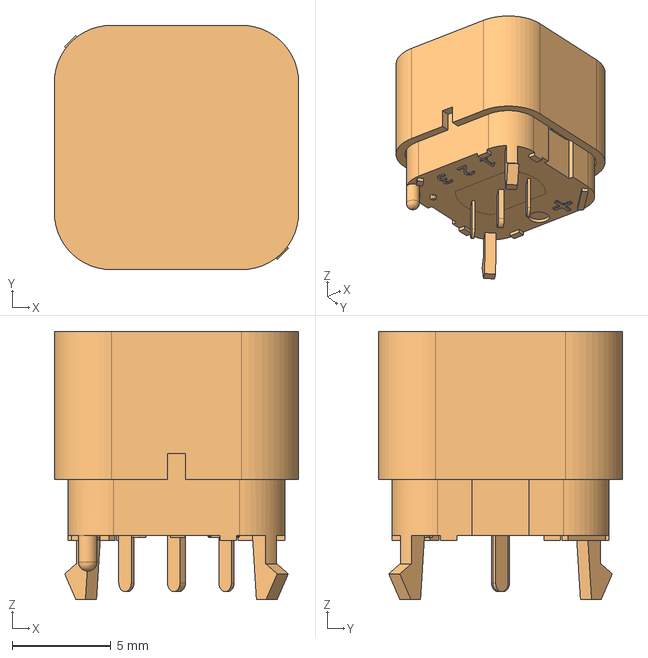
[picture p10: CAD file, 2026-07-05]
Mechanical/Components/PB300DTQ/PB300DTQ.step
12.4 x 12.4 x 13.6 mm

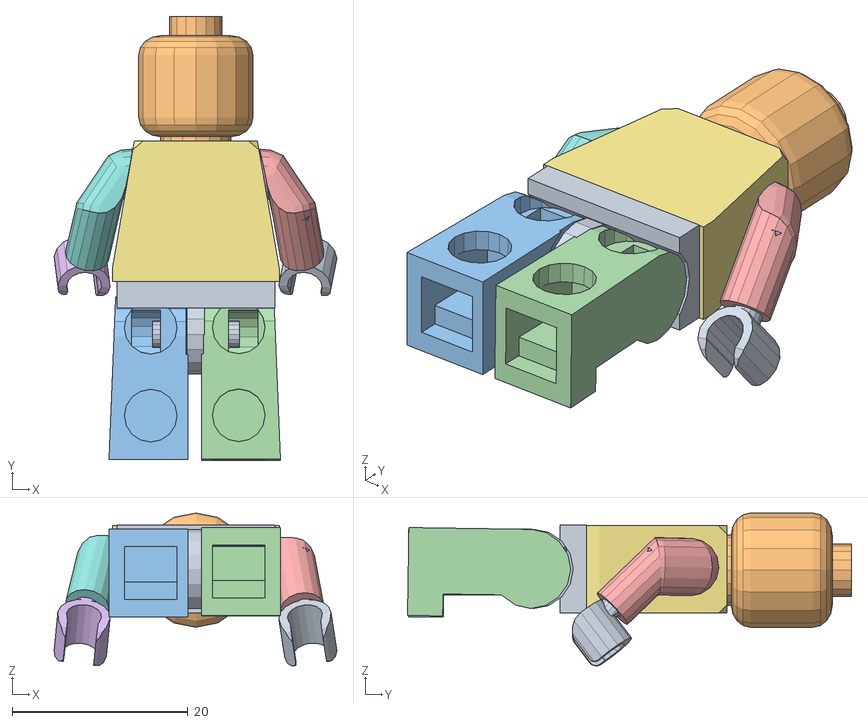
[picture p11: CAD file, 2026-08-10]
Mechanical/Components/source/Lego_Minifigure.obj
32.2 x 50.5 x 17.4
Hips_Part-3815_dot_dat
Head_Part-3626b_dot_dat
LLeg_Part-3816_dot_dat
RLeg_Part-3817_dot_dat
RArm_Part-3819_dot_dat
LHand_Part-3820_dot_dat
Torso_Part-973_dot_dat
LArm_Part-3819_dot_dat.001
RHand_Part-3820_dot_dat.001

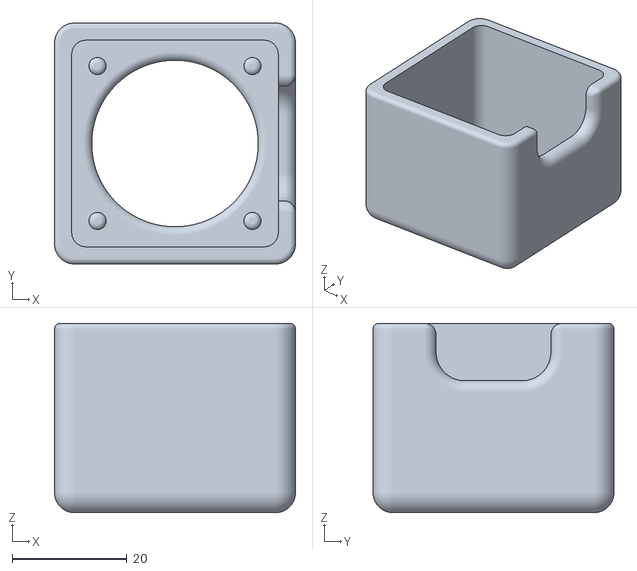
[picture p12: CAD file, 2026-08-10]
Mechanical/CAD/Top Cover - FINAL.stl
42.0 x 42.0 x 33.0

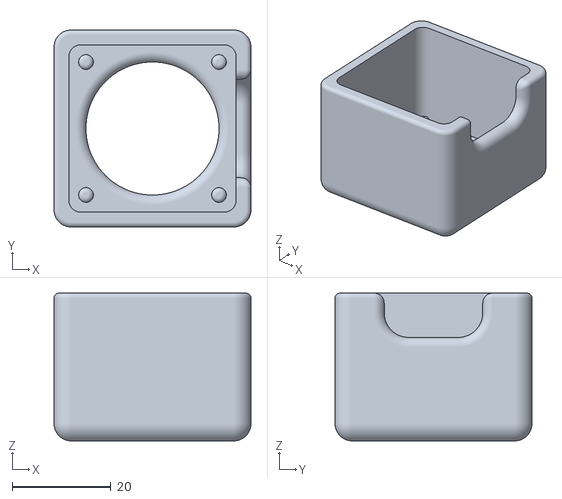
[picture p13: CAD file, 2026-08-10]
Mechanical/CAD/Top Cover - V1.stl
40.0 x 40.0 x 30.0

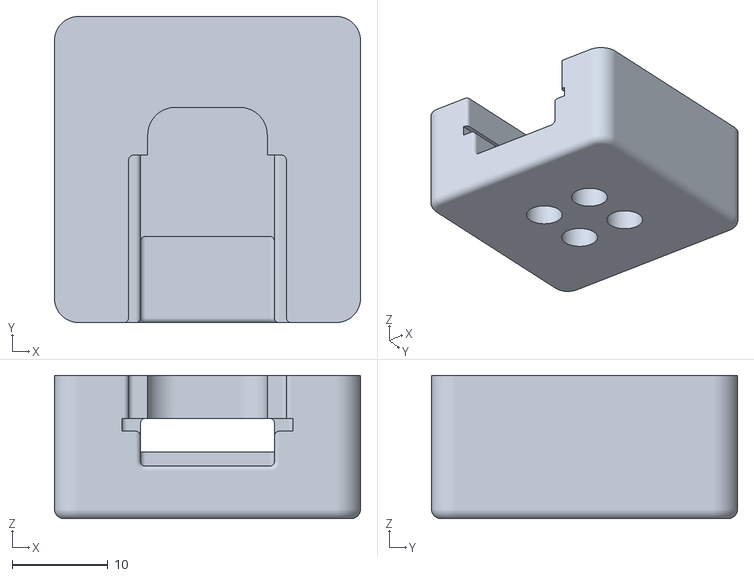
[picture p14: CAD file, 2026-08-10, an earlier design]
Mechanical/CAD/Main Housing - V1.stl
32.0 x 32.0 x 15.0

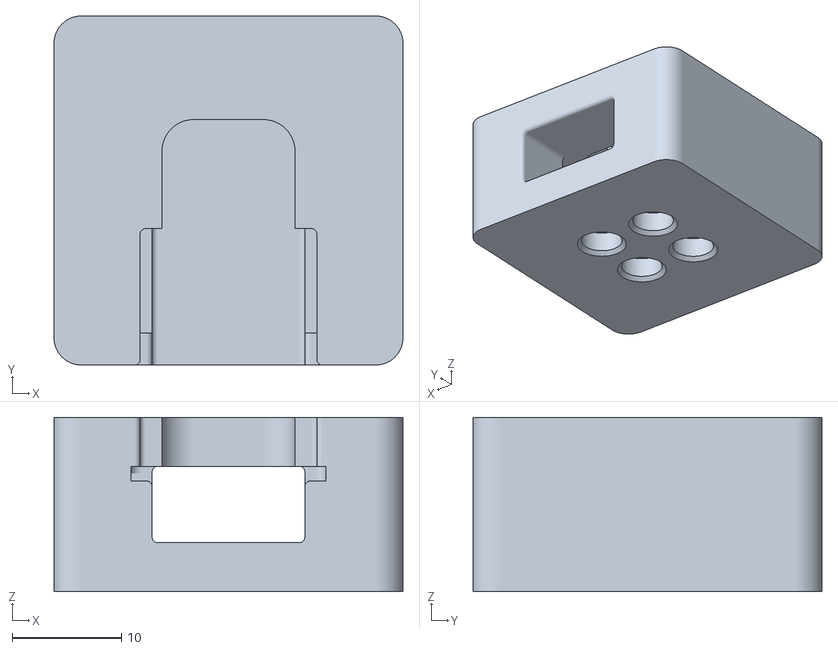
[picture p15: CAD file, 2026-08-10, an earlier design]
Mechanical/CAD/Main Housing - V5.stl
32.0 x 32.0 x 16.0

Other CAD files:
Mechanical/CAD/Button Board - V5.stl
Mechanical/CAD/Main Housing - V4.stl
Mechanical/CAD/Main Housing - V3.stl
Mechanical/CAD/Main Housing - V2.stl
Mechanical/CAD/Button Board - V4.stl
Mechanical/CAD/Button Board - V2.stl
Mechanical/CAD/Button Board - V1.stl
Mechanical/CAD/Button Board - V3.stl
Mechanical/Components/13282/sparkfun 3D_Models master products-11820/geometry_edit_blender/boardpost.blend
Mechanical/Components/13282/sparkfun 3D_Models master products-11820/geometry_edit_blender/ws2812-Breakout.blend
Mechanical/Components/13282/sparkfun 3D_Models master products-11820/skp/ws2812-Breakout.skp

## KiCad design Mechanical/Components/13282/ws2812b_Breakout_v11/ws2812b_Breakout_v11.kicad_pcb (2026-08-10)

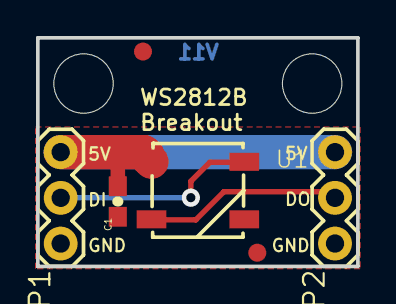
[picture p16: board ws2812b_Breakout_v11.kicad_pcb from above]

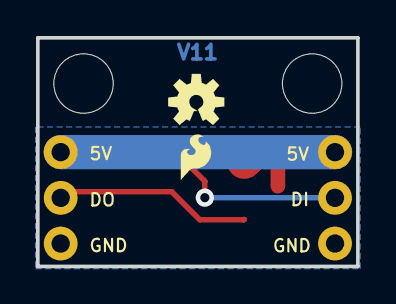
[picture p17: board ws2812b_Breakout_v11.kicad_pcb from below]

Board: 2 copper layers, 17.8 x 12.7 mm, 11 parts (2 on the bottom side), 4 nets.

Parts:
C1: 0.1uF; 0603-CAP
FID1, FID2: FIDUCIAL1X2; FIDUCIAL-1X2
FRAME1: CREATIVE_COMMONS
JP1: INPUT; 1X03
JP2: OUTPUT; 1X03
JP4, JP15: STAND-OFF
LOGO1: OSHW-LOGOS; OSHW-LOGO-S
LOGO2: SFE_LOGO_FLAME.1_INCH; SFE_LOGO_FLAME_.1
U1: WS2812B

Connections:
DI: JP1.2, U1.4
DO: JP2.2, U1.2
GND: C1.1, JP1.1, JP2.1, U1.3
VCC: C1.2, JP1.3, JP2.3, U1.1

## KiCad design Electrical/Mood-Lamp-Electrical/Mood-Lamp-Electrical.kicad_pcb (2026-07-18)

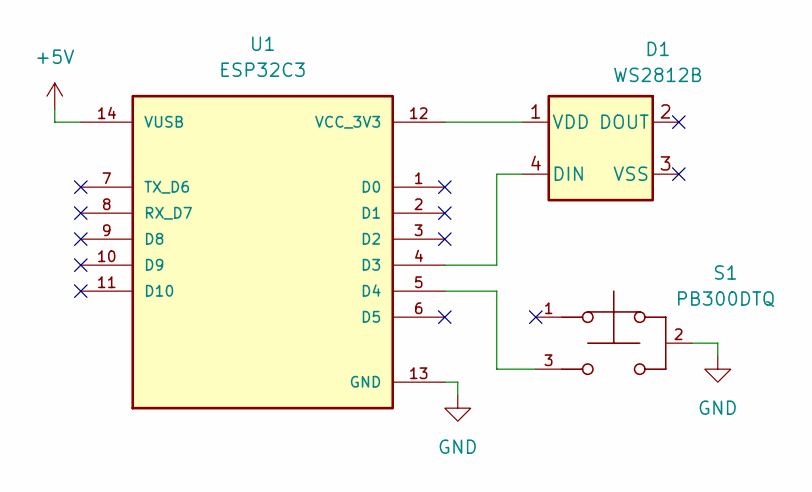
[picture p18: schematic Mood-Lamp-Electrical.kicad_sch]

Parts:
D1: WS2812B; LED_WS2812B_PLCC4_5.0x5.0mm_P3.2mm
S1: PB300DTQ; SW_PB300DTQ
U1: ESP32C3; MODULE_113991054; PARTREV 23/05/2022

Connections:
+5V: U1.14 (VUSB)
GND: S1.2, U1.13 (GND)
unnamed: D1.4 (DIN), U1.4 (D3)
unnamed: D1.1 (VDD), U1.12 (VCC_3V3)
unnamed: S1.3, U1.5 (D4)

Board: 2 copper layers, 3 parts (0 on the bottom side), 4 nets, no tracks yet.

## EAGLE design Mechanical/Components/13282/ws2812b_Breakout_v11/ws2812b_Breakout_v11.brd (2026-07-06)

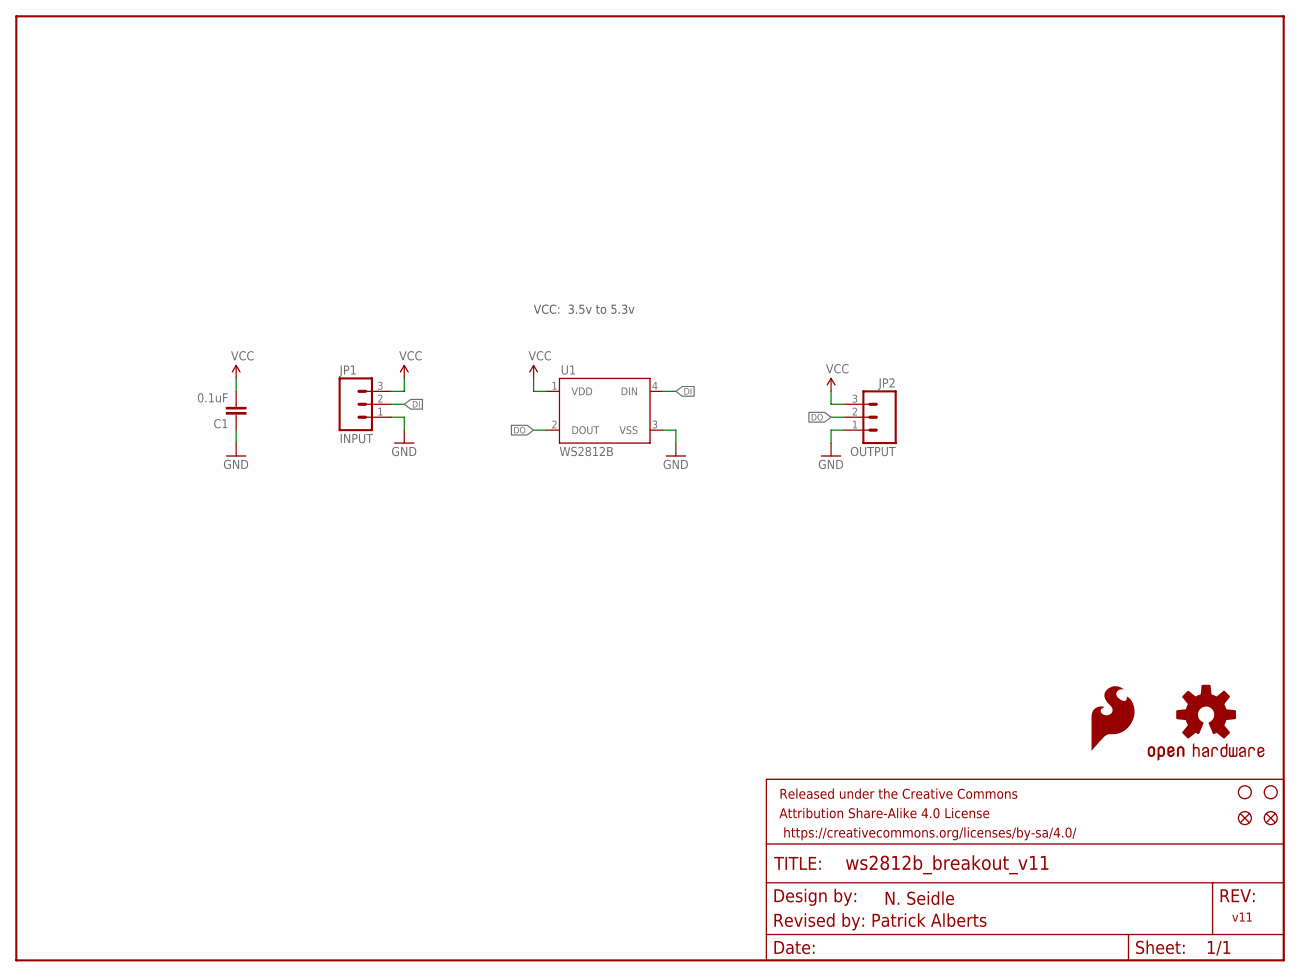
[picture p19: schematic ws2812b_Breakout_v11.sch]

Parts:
C1: 0.1uF; 0603-CAP
FID1, FID2: FIDUCIAL1X2; FIDUCIAL-1X2
FRAME1: FRAME-LETTER; CREATIVE_COMMONS
JP1: INPUT; 1X03
JP2: OUTPUT; 1X03
JP4, JP15: STAND-OFF
LOGO1: OSHW-LOGOS; OSHW-LOGO-S
LOGO2: SFE_LOGO_FLAME.1_INCH; SFE_LOGO_FLAME_.1
U1: WS2812B

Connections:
DI: JP1.2, U1.4 (DIN)
DO: JP2.2, U1.2 (DOUT)
GND: C1.1, JP1.1, JP2.1, U1.3 (VSS)
VCC: C1.2, JP1.3, JP2.3, U1.1 (VDD)

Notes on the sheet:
v11
N. Seidle
Revised by: Patrick Alberts
VCC: 3.5v to 5.3v

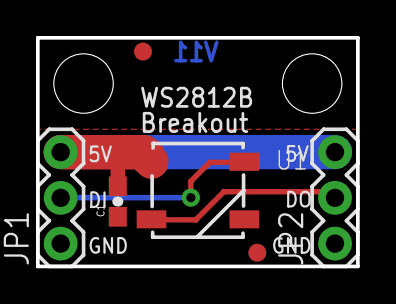
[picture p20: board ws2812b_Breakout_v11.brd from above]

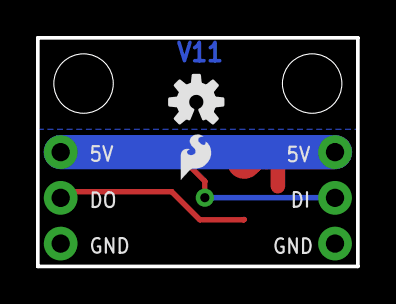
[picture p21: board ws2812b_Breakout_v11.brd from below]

Board: 2 copper layers, 17.8 x 12.7 mm, 11 parts (2 on the bottom side), 4 nets.

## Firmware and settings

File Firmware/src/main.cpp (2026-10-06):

/**************************************************************************************************/
/**
 * @file main.cpp
 * @author  Ryan Jing
 * @brief Firmware entry point: initialises hardware and spawns the lamp and comms tasks.
 *
 * @version 0.1
 * @date 2026-07-03
 *
 * @copyright Copyright (c) 2026
 *
 */
/**************************************************************************************************/

/*------------------------------------------------------------------------------------------------*/
/* HEADERS                                                                                        */
/*------------------------------------------------------------------------------------------------*/

#include <Arduino.h>

#include "moods.h"
#include "state.h"
#include "config.h"
#include "hal/led.h"
#include "hal/button.h"
#include "net/wifi.h"
#include "net/ble.h"
#include "net/api.h"

/*------------------------------------------------------------------------------------------------*/
/* MACROS                                                                                         */
/*------------------------------------------------------------------------------------------------*/

#define LAMP_TASK_STACK_SIZE 4096
#define COMMS_TASK_STACK_SIZE 16384

/*------------------------------------------------------------------------------------------------*/
/* GLOBAL VARIABLES                                                                               */
/*------------------------------------------------------------------------------------------------*/



/*----------------------------------------------------------------------------------------------*/
/* FUNCTION PROTOTYPES                                                                            */
/*------------------------------------------------------------------------------------------------*/

/**************************************************************************************************/
/**
 * @name
 * @brief Initialise the lamp task's state and its hardware (button and LED).
 *
 *
 *
 */
/**************************************************************************************************/
void lamp_application_init(LampState &lamp_state);

/**************************************************************************************************/
/**
 * @name
 * @brief Initialise the comms task's state and choose the starting connection status.
 *
 *
 * @param net_state
 *
 */
/**************************************************************************************************/
void net_application_init(NetState &net_state);

/**************************************************************************************************/
/**
 * @name
 * @brief FreeRTOS task: run the button/LED state machine and render the current mood.
 *
 *
 * @param pvParameters
 *
 */
/**************************************************************************************************/
void vLampTask(void *pvParameters);

/**************************************************************************************************/
/**
 * @name
 * @brief FreeRTOS task: manage BLE provisioning, Wi-Fi, and server sync.
 *
 *
 * @param pvParameters
 *
 */
/**************************************************************************************************/
void vCommsTask(void *pvParameters);

/*------------------------------------------------------------------------------------------------*/
/* FUNCTION DEFINITIONS                                                                           */
/*------------------------------------------------------------------------------------------------*/

static void set_shared_comms_status(NetState &set_net_state, CommsStatus set_comms_status) {
    if (set_comms_status == BLE_PROVISIONING) {
        set_net_state.ble_provisioning_started_ms = millis();
    }
    else {
        set_net_state.ble_provisioning_started_ms = 0;
    }

    set_net_state.comms_status = set_comms_status;
    shared_set_net_state(set_comms_status);
}

static bool has_saved_wifi_credentials(NetState &net_state) {
    return get_wifi_credentials(net_state.wifi_credentials);
}

static void stop_ble_and_resume_network(NetState &net_state) {
    if (net_state.comms_status == BLE_PROVISIONING ||
        net_state.comms_status == BLE_CONNECTED) {
        ble_provisioning_stop();
    }

    net_state.poll_retry_count = 0;

    if (has_saved_wifi_credentials(net_state)) {
        set_shared_comms_status(net_state, NET_CONNECTING);
    }
    else {
        set_shared_comms_status(net_state, NET_DISCONNECTED);
    }
}

void vLampTask(void *pvParameters) {
    LampState lamp_state;
    lamp_application_init(lamp_state);

    for (;;) {
        Moods mood_to_render = lamp_state.peer_mood;

        lamp_state.current_time = millis();
        get_button_state(&lamp_state.button_state);
        update_button_event(lamp_state);

        bool button_consumed = handle_user_button_commands(lamp_state);
        CommsStatus comms_status = shared_get_net_state();

        if (lamp_state.application_state == SELECT_MOOD && comms_status != NET_CONNECTED) {
            lamp_state.application_state = SHOW_MOOD;
            lamp_state.button_press_time = 0;
            lamp_state.full_press_time = 0;
        }

        if (lamp_state.application_state != SELECT_MOOD) {
            switch (comms_status) {
                case BLE_PROVISIONING:
                    lamp_state.application_state = BLE_STATUS;
                    break;

                case BLE_CONNECTED:
                    lamp_state.application_state = BLE_STATUS;
                    break;

                case NET_DISCONNECTED:
                    lamp_state.application_state = SHOW_MOOD;
                    break;

                case NET_CONNECTING:
                    lamp_state.application_state = SHOW_MOOD;
                    break;

                case NET_CONNECTED:
                    lamp_state.application_state = SHOW_MOOD;
                    break;

                default:
                    lamp_state.application_state = SHOW_MOOD;
                    break;
            }
        }

        switch (lamp_state.application_state) {

            #ifdef PRINT_DEBUG
                Serial.print("Current application state: ");
                Serial.println(lamp_state.application_state);
            #endif

            case BLE_STATUS:
                mood_to_render = BLE;
                break;

            case NET_STATUS:
                mood_to_render = NO_WIFI;
                break;

            case SHOW_MOOD:
                if (!button_consumed) {
                    show_mood_button_handle(lamp_state);
                }

                if (comms_status == NET_CONNECTED) {
                    lamp_state.peer_mood = shared_get_peer_mood();
                }
                else if (comms_status == NET_DISCONNECTED || comms_status == NET_CONNECTING) {
                    lamp_state.peer_mood = IDLE;
                }

                mood_to_render = lamp_state.peer_mood;
                break;

            case SELECT_MOOD:
                if (!button_consumed) {
                    select_mood_button_handle(lamp_state);
                }

                mood_to_render = lamp_state.self_mood;
                break;
            }

        led_render(mood_to_render);
        vTaskDelay(pdMS_TO_TICKS(10));
    }
}

void vCommsTask(void *pvParameters) {
    NetState net_state;
    net_application_init(net_state);

    if (net_state.comms_status == BLE_PROVISIONING) {
        ble_provisioning_start();
    }

    for (;;) {
        UserCommand user_command;
        if (shared_take_user_command(&user_command)) {

            #ifdef PRINT_DEBUG
                Serial.print("User command received: ");
                Serial.println(user_command);
            #endif

            switch (user_command) {
                case USER_COMMAND_START_BLE:
                    if (net_state.comms_status != BLE_PROVISIONING &&
                        net_state.comms_status != BLE_CONNECTED) {
                        wifi_disconnect();
                        ble_provisioning_start();
                        set_shared_comms_status(net_state, BLE_PROVISIONING);
                    }
                    break;

                case USER_COMMAND_STOP_BLE:
                    stop_ble_and_resume_network(net_state);
                    break;

                case USER_COMMAND_CLEAR_WIFI:
                    if (net_state.comms_status == BLE_PROVISIONING ||
                        net_state.comms_status == BLE_CONNECTED) {
                        ble_provisioning_stop();
                    }

                    clear_wifi_credentials();
                    wifi_disconnect();
                    ble_provisioning_start();
                    net_state.poll_retry_count = 0;
                    set_shared_comms_status(net_state, BLE_PROVISIONING);
                    break;

                default:
                    break;
            }
        }

        switch (net_state.comms_status) {
            case BLE_PROVISIONING:
                if (ble_is_connected()) {
                    set_shared_comms_status(net_state, BLE_CONNECTED);
                }
                else if (millis() - net_state.ble_provisioning_started_ms >=
                         BLE_PROVISIONING_TIMEOUT_MS) {
                    stop_ble_and_resume_network(net_state);
                }
                break;

            case BLE_CONNECTED:
                if (ble_take_credentials(net_state.wifi_credentials)) {
                    save_wifi_credentials(net_state.wifi_credentials);

                    ble_set_status("connecting");
                    vTaskDelay(pdMS_TO_TICKS(300));
                    ble_provisioning_stop();

                    set_shared_comms_status(net_state, NET_CONNECTING);

                    #ifdef PRINT_DEBUG
                        Serial.println("Wi-Fi credentials saved via BLE");
                        Serial.print("SSID: ");
                        Serial.println(net_state.wifi_credentials.ssid);
                        Serial.print("Password: ");
                        Serial.println(net_state.wifi_credentials.password);
                    #endif

                } else if (!ble_is_connected()) {
                    set_shared_comms_status(net_state, BLE_PROVISIONING);
                }
                break;

            case NET_CONNECTING:
                if (wifi_connect(net_state.wifi_credentials, WIFI_CONNECT_TIMEOUT_MS)) {
                    if (!api_wait_for_time(SNTP_TIMEOUT_MS)) {
                        wifi_disconnect();
                        vTaskDelay(pdMS_TO_TICKS(WIFI_RETRY_DELAY_MS));

                        break;
                    }

                    set_shared_comms_status(net_state, NET_CONNECTED);
                    net_state.last_peer_poll_ms = 0;
                    net_state.poll_retry_count = 0;

                    #ifdef PRINT_DEBUG
                        Serial.println("Wi-Fi connected");
                    #endif
                }

                else {
                    wifi_disconnect();
                    vTaskDelay(pdMS_TO_TICKS(WIFI_RETRY_DELAY_MS));
                }
                break;

            case NET_CONNECTED: {
                if (!wifi_is_connected()) {
                    wifi_disconnect();
                    set_shared_comms_status(net_state, NET_CONNECTING);
                    break;
                }

                Moods posted_mood;

                if (shared_get_posted_mood(&posted_mood)) {
                    net_state.mood_to_post = posted_mood;
                    net_state.has_mood_to_post = true;
                }

                if (net_state.has_mood_to_post) {
                    if (api_post_mood(net_state.mood_to_post) == API_OK) {
                        net_state.has_mood_to_post = false;
                        net_state.poll_retry_count = 0;

                        #ifdef PRINT_DEBUG
                            Serial.print("Mood posted successfully: ");
                            Serial.println(net_state.mood_to_post);
                        #endif
                    }

                    else {
                        net_state.poll_retry_count++;
                    }
                }

                uint32_t now = millis();

                if (net_state.last_peer_poll_ms == 0 ||
                    now - net_state.last_peer_poll_ms >= PEER_POLL_INTERVAL_MS) {
                    net_state.last_peer_poll_ms = now;

                    Moods peer_mood;
                    uint32_t new_version = net_state.peer_version;

                    ApiResult result = api_get_peer_mood(net_state.peer_version, peer_mood, new_version);

                    if (result == API_OK) {
                        net_state.peer_mood = peer_mood;
                        net_state.peer_version = new_version;
                        shared_set_peer_mood(peer_mood);
                        net_state.poll_retry_count = 0;

                        #ifdef PRINT_DEBUG
                            Serial.print("Showing new peer mood updated: ");
                            Serial.println(peer_mood);
                        #endif
                    }

                    else if (result == API_NOT_MODIFIED) {
                        net_state.poll_retry_count = 0;
                    }

                    else {
                        net_state.poll_retry_count++;
                    }
                }

                if (net_state.poll_retry_count >= API_RETRY_LIMIT) {
                    wifi_disconnect();
                    set_shared_comms_status(net_state, NET_CONNECTING);
                }
                break;
            }

            case NET_DISCONNECTED:
                break;

            default:
                break;
        }

        vTaskDelay(pdMS_TO_TICKS(10));
    }
}

void lamp_application_init(LampState &lamp_state) {
    setup_button();
    led_init();
    lamp_state.self_mood = MOOD_1;
    lamp_state.peer_mood = shared_get_peer_mood();
    lamp_state.application_state = SHOW_MOOD; // Show default mood pattern on startup
    lamp_state.button_state = BUTTON_RELEASED;
    lamp_state.button_event = BUTTON_EVENT_NONE;
    lamp_state.button_press_time = 0;
    lamp_state.full_press_time = 0;
    lamp_state.current_time = millis();
}

void net_application_init(NetState &net_state) {
    net_state.peer_mood = MOOD_1;
    net_state.mood_to_post = MOOD_1;
    net_state.peer_version = 0;
    net_state.last_peer_poll_ms = 0;
    net_state.ble_provisioning_started_ms = 0;
    net_state.poll_retry_count = 0;
    net_state.has_mood_to_post = false;

    if (!get_wifi_credentials(net_state.wifi_credentials)) {
        set_shared_comms_status(net_state, BLE_PROVISIONING);
    }
    else {
        set_shared_comms_status(net_state, NET_CONNECTING);

        #ifdef PRINT_DEBUG
            Serial.println("Wi-Fi credentials found in NVS");
            Serial.print("SSID: ");
            Serial.println(net_state.wifi_credentials.ssid);
            Serial.print("Password: ");
            Serial.println(net_state.wifi_credentials.password);
        #endif
    }
}

void setup() {
    Serial.begin(115200);

    #if defined(PRINT_DEBUG)
        delay(2000);
        Serial.println("Mood Lamp Firmware v0.1");
    #endif

    shared_state_init();

    BaseType_t xLampReturned;
    BaseType_t xCommsTask;

    xLampReturned = xTaskCreate(vLampTask,
                                "Lamp Task",
                                LAMP_TASK_STACK_SIZE,
                                nullptr,
                                1,
                                nullptr);

    xCommsTask = xTaskCreate(vCommsTask,
                             "Comms Task",
                             COMMS_TASK_STACK_SIZE,
                             nullptr,
                             1,
                             nullptr);
}

void loop() {
    vTaskDelay(pdMS_TO_TICKS(1000));
}

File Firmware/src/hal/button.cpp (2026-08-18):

/**************************************************************************************************/
/**
 * @file button.cpp
 * @author  Ryan Jing
 * @brief Debounced dual-stage button input and per-state gesture handling implementation.
 *
 * @version 0.1
 * @date 2026-07-03
 *
 * @copyright Copyright (c) 2026
 *
 */
/**************************************************************************************************/

/*------------------------------------------------------------------------------------------------*/
/* HEADERS                                                                                        */
/*------------------------------------------------------------------------------------------------*/

#include "hal/button.h"

#include <Arduino.h>

#include "state.h"
#include "config.h"

/*------------------------------------------------------------------------------------------------*/
/* MACROS                                                                                         */
/*------------------------------------------------------------------------------------------------*/


/*------------------------------------------------------------------------------------------------*/
/* GLOBAL VARIABLES                                                                               */
/*------------------------------------------------------------------------------------------------*/

const int button_position_one = D2;  // Half-press stage (button pin 2), active low
const int button_position_two = D1;  // Full-press stage (button pin 3), active low

/*------------------------------------------------------------------------------------------------*/
/* FUNCTION PROTOTYPES                                                                            */
/*------------------------------------------------------------------------------------------------*/



/*------------------------------------------------------------------------------------------------*/
/* FUNCTION DEFINITIONS                                                                           */
/*------------------------------------------------------------------------------------------------*/

void setup_button() {
    pinMode(button_position_one, INPUT_PULLUP);
    pinMode(button_position_two, INPUT_PULLUP);
}

void get_button_state(ButtonState *state) {
    const uint32_t debounce_delay = 50;

    static int stable_one_value = HIGH;
    static int stable_two_value = HIGH;
    static int last_raw_one_value = HIGH;
    static int last_raw_two_value = HIGH;
    static uint32_t last_debounce_one_time = 0;
    static uint32_t last_debounce_two_time = 0;

    int raw_one_value = digitalRead(button_position_one);
    int raw_two_value = digitalRead(button_position_two);

    if (raw_one_value != last_raw_one_value) {
        last_raw_one_value = raw_one_value;
        last_debounce_one_time = millis();
    }

    if (raw_two_value != last_raw_two_value) {
        last_raw_two_value = raw_two_value;
        last_debounce_two_time = millis();
    }

    if ((millis() - last_debounce_one_time) > debounce_delay) {
        stable_one_value = raw_one_value;
    }

    if ((millis() - last_debounce_two_time) > debounce_delay) {
        stable_two_value = raw_two_value;
    }

    // A full press grounds both stages, so the full stage alone decides FULL_PRESSED.
    if (stable_two_value == LOW) {
        *state = BUTTON_FULL_PRESSED;
    }
    else if (stable_one_value == LOW) {
        *state = BUTTON_HALF_PRESSED;
    }
    else {
        *state = BUTTON_RELEASED;
    }
}

void update_button_event(LampState &s) {
    s.button_event = BUTTON_EVENT_NONE;

    if (s.button_state != BUTTON_RELEASED) {
        if (s.button_press_time == 0) {
            s.button_press_time = s.current_time;
        }

        // A full press passes through the half stage on the way down and back up, so
        // latch when full is first reached; release below uses it to tell a half tap
        // from a full press, and hold time is measured from full engagement.
        if (s.button_state == BUTTON_FULL_PRESSED && s.full_press_time == 0) {
            s.full_press_time = s.current_time;
        }

        return;
    }

    if (s.button_press_time == 0) {
        return;
    }

    if (s.full_press_time != 0) {
        uint32_t held = s.current_time - s.full_press_time;

        if (held >= WIFI_CLEAR_TIMER * 1000) {
            s.button_event = BUTTON_EVENT_FULL_HOLD_WIFI;
        }
        else if (held >= BLE_SET_TIMER * 1000) {
            s.button_event = BUTTON_EVENT_FULL_HOLD_BLE;
        }
        else {
            s.button_event = BUTTON_EVENT_FULL_TAP;
        }
    }
    else {
        s.button_event = BUTTON_EVENT_HALF_TAP;
    }

    s.button_press_time = 0;
    s.full_press_time = 0;
}

bool handle_user_button_commands(LampState &s) {
    switch (s.button_event) {
        case BUTTON_EVENT_FULL_HOLD_WIFI:
            shared_post_user_command(USER_COMMAND_CLEAR_WIFI);
            s.application_state = SHOW_MOOD;

            #ifdef PRINT_DEBUG
                Serial.println("User command: Wi-Fi credentials cleared");
            #endif

            return true;

        case BUTTON_EVENT_FULL_HOLD_BLE: {
            CommsStatus comms_status = shared_get_net_state();

            if (comms_status == BLE_PROVISIONING || comms_status == BLE_CONNECTED) {
                shared_post_user_command(USER_COMMAND_STOP_BLE);

                #ifdef PRINT_DEBUG
                    Serial.println("User command: BLE stopped");
                #endif
            }
            else {
                shared_post_user_command(USER_COMMAND_START_BLE);

                #ifdef PRINT_DEBUG
                    Serial.println("User command: BLE started");
                #endif
            }

            s.application_state = SHOW_MOOD;
            return true;
        }

        case BUTTON_EVENT_FULL_TAP: {
            CommsStatus comms_status = shared_get_net_state();

            // A single full tap is enough to leave BLE provisioning; no hold needed.
            if (comms_status == BLE_PROVISIONING || comms_status == BLE_CONNECTED) {
                shared_post_user_command(USER_COMMAND_STOP_BLE);
                s.application_state = SHOW_MOOD;

                #ifdef PRINT_DEBUG
                    Serial.println("User command: BLE stopped");
                #endif

                return true;
            }

            return false;
        }

        default:
            return false;
    }
}

void show_mood_button_handle(LampState &s) {
    // Half taps do nothing here; they only cycle moods in SELECT_MOOD.
    if (s.button_event == BUTTON_EVENT_FULL_TAP &&
        shared_get_net_state() == NET_CONNECTED) {
        s.application_state = SELECT_MOOD;

        #ifdef PRINT_DEBUG
            Serial.println("User command: Select mood mode");
        #endif
    }
}
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

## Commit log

2026-07-06 Moods defined
    [boardpost.blend, ws2812-Breakout.blend, ws2812-Breakout.skp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]
2026-07-07 Led implementation updates for firmware tests
2026-07-08 Updated docs and prints
2026-07-18 Simple schematic
    [Mood-Lamp-Electrical.kicad_pcb, Mood-Lamp-Electrical.kicad_sch, WS2812_Breakout.step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]
2026-08-10 CAD and firmware changes
    [Button Board - V1.stl, Button Board - V2.stl, Button Board - V3.stl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]
2026-08-12 pinout changes
    [Button Board - FINAL.stl, Main Housing - FINAL.stl, Top Cover - FINAL.stl]
2026-08-18 Updated moods and patterns
    [Mood-Lamp-Electrical.kicad_sch]

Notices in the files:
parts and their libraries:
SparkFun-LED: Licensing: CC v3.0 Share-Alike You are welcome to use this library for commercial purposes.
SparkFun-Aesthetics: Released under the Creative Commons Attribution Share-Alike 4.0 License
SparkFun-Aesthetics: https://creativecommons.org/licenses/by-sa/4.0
